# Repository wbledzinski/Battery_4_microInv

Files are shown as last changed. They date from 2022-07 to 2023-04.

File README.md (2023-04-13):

# Battery controller for On-grid microinverter 
36V li-ion battery controller cooperating with grid-tied microinverter
## 10A 35-42V battery; 450W grid-tie microinverter

2nd version of controller HW, connected to Microinverter and four e-scooter batteries
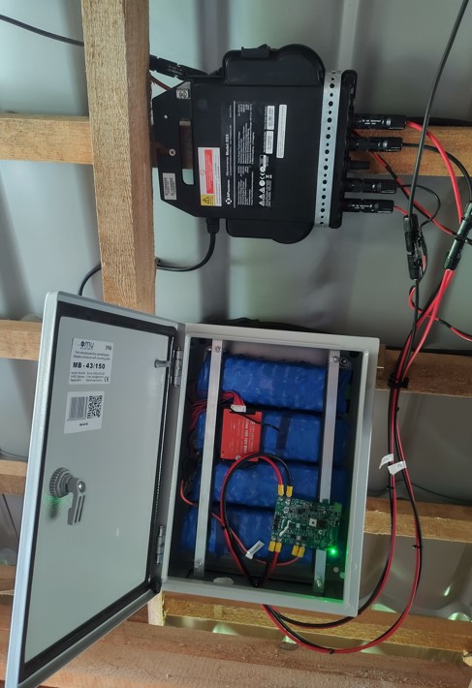
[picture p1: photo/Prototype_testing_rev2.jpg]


###  About this project
Main idea is to connect 10S 36V/42V li-ion e-scooter/e-bike battery to grid-tied PV installation.
It can be done because microinverters use low voltage input (MPP is ~40V).
So e-scooter battery has voltage exactly in operational range of microinverter and PV panel.

###  What exactly does this device?
Monitors energy consumption by microinverter. In case of inverter fault this device stores PV energy in battery.
After dusk energy stored in battery might be tranfered via inverter to mains network.

###  Why that idea?
It's because photovoltaics is very popular in village area where i've built my house. The result is that mains voltage is to high to properly operate any inverter around noon on sunny, cloudless day.

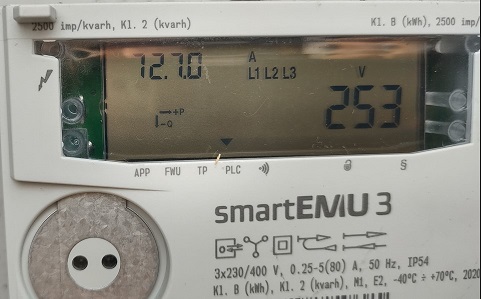
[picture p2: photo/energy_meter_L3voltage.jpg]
Energy meter phase L3 voltage measurement, during *inverters fight*


During sunny day my inverters (and neighbours' as well) switch off several times. That causes loses in energy production, because at possible peak production my PV array does not generate energy at all. 

Solution is to detect inverter fault and switch PV to charge battery - at the same time waiting for inverter to recover. Usually it's less than 10 minutes. But it happens dozens times during sunny day. Energy from battery is transferred to inverter (and mains) after dusk.

###  Modes of operation

user can configure controller in 3 modes:
- 1st mode is to tranfer energy from PV to inverter, charge battery only when inverter cautches fault; finally after dusk controller connects battery to microinverter to transfer stored  energy from battery to mains
- 2nd mode is to store energy in battery and connect inverter when battery is full. Then it will discharge battery after dusk
- 3rd mode is to tranfer energy from PV to inverter, charge battery only when inverter cautches fault; no battery discharge

###  Delayed discharge
My 2kW PV installation based on microinverters, uses 5 PV panels, 11A each, and 5 microinverters.
Connecting 5 batteries with controllers, I can set discharge delay independently for each controller.
result is that i can discharge them one by one thru the night, making it possible to consume that energy by fridge, lighting and other appliances.

###  Operation statistics
Firmware has built-in statistics counters, to estimate amount of energy transfered, recovered, number of microinverter faults

It suprised me, but statistics shows that some inverters have more faults than others, despite that they are all connected in parallel to the same electrical network

Real statistics after 3 days of operation:
------------------------------------------
Battery size 20Ah 10S battery, summertime, single energy bank:
- Inverter not operational 14587 seconds
- energy stored in battery due to lack of inverter operation; Wh 1781
- energy transferred from battery after dusk: Wh 1003
- energy transferred from PV to microinverter: Wh 8000
- number of inverter reset procedure launches: 6 (inverter not working > 30minutes)

Real statistics, from dec 2022 to apr 2023:
-----------------------------------------
Battery size 20Ah 10S battery, wintertime, single energy bank:
- Inverter not operational 655876 seconds (182 hours)
- battery too cold to charge 336885 seconds (93 hours) - energy not transfered to mains and not stored in battery (too cold)
- energy transferred from battery after dusk: Wh 16250
- energy transferred from PV to microinverter: Wh 84890

###  What it really does
below you see energy consumption and production as it's seen by energy distribution company.
blue is consumption, pink is production. Marked in red is what my system generates after dusk.
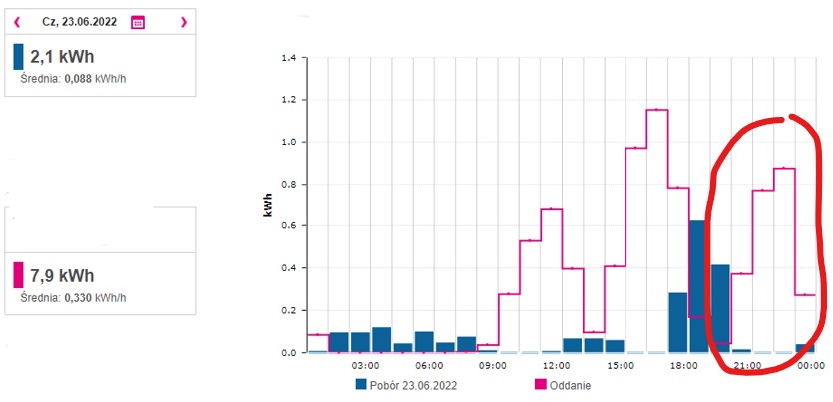
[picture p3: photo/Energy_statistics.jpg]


###  This version is in testing phase
A few pieces assembled, in-field testing in progress.

### Simplified operation algorithm
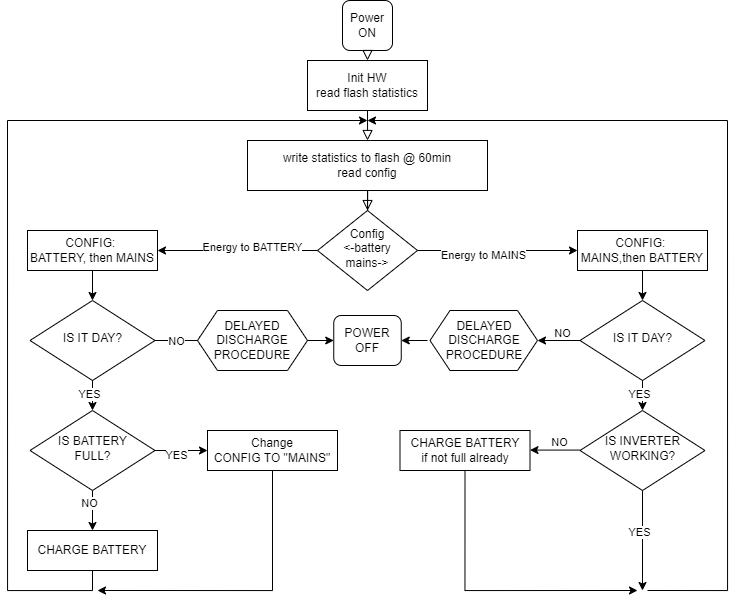
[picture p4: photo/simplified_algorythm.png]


###  what is working
- monitors Inverter operation, connects battery when inverter not operational
- after sunset properly counts delay time and after timeout connects battery to microinverter
- controls current consumption by microinverter, during daytime to decide whether charge battery or not
- controls current consumption by microinverter, during nighttime, to prevent excessive current consumption from battery: sometimes it happens -> controller resets microinverter MPP by cycling power
- overtemperature protection
- recent version (nov 2022) added under temperature charging protection

###  what is not working or not implemented
- ESP32, not implemented, HW 3v3 voltage rail is too weak to supply ESP32
- no implementation of any kind of watchdog
- no implementation of any kind of power saving mode
- SD-Card logging not implemented (to create detailed statistics or charts later)
- no RTC, might be usefull to create detailed statistics

###  HW Testing: Battery discharge
below is Pic during battery discharge ~13A, HW rev 01
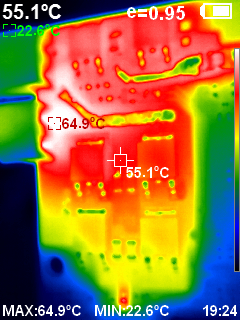
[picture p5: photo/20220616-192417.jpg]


below is Pic during battery discharge ~12A, HW rev 02
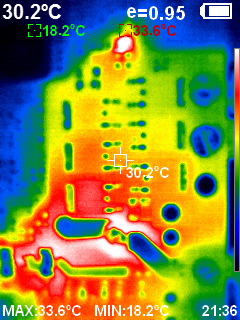
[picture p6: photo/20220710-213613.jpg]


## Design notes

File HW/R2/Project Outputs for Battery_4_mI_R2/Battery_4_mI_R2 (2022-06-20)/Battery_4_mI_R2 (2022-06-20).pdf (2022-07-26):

Comment | Description | Designator | Footprint | LibRef | LogicalDesignator | Manufacturer | Manufacturer 1 | Manufacturer 2 | Manufacturer Part Number | Manufacturer Part Number 1 | Manufacturer Part Number 2 | PartType | Price10 | Price1k | Pricing | Quantity | Supplier | Supplier 1 | Supplier 2 | Supplier Currency 1 | Supplier Currency 2 | Supplier Order Qty 1 | Supplier Order Qty 2 | Supplier Part Number | Supplier Part Number 1 | Supplier Part Number 2 | Supplier Stock 1 | Supplier Stock 2 | Supplier Subtotal 1 | Supplier Subtotal 2 | Supplier Unit Price 1 | Supplier Unit Price 2 | Value | Layer
1u/100 | X7R chip capacitor | C1, C2, C3, C28, C29 | CAP_1206 | CAP_B_1u_100_1 206_X7R | C1, C2, C3, C28, C29 | AVX | | | 12061C105KAT2A | | | 1u/100 | 0.22 | 0.2 | | 5 | TME | FARNELL | | | | | | 12061C105KAT2A | 2112837 | | | | | | | | 1u/100 | Top
4.7u/25 | X5R chip capacitor | C4, C5 | CAP_1210 | CAP_B_4.7u_25_1 210_X5R | C4, C5 | YAGEO | | | CC1210KKX5R8BB 475 | | | 4.7u/25 | 0.17 | 0.007 | | 2 | TME | Farnell | | | | | | CC1210KKX5R847 5 | 1833828 | | | | | | | | 4.7u/25 | Top
100n/50 | X7R chip capacitor | C6, C11, C12, C22, C23, C26, C32, C35, C38, C39, C40, C41, C42, C44 | CAP_0603 | CAP_B_100n_50_ 0603_X7R | C6, C11, C12, C22, C23, C26, C32, C35, C38, C39, C40, C41, C42, C44 | SAMSUNG | | | CL10B104KB8NNN C | | | 100n/50 | 0.1 | 0.006 | | 14 | TME | | | | | | | CL10B104KB8NNN C | | | | | | | | | 100n/50 | Top, Bottom
10u/25 | X5R chip capacitor | C7 | CAP_1206 | CAP_B_10u_25_1 206_X5R | C7 | SAMSUNG | | | CL31A106KAHNN NE | | | 10u/25 | 0.08 | 0.045 | | 1 | TME | Farnell | | | | | | CL31A106KAHNN NE | 2426961 | | | | | | | | 10u/25 | Top
10u/16 | X7R chip capacitor | C8, C9, C10, C27, C30 | CAP_1206 | CAP_B_10u_16_1 206_X7R | C8, C9, C10, C27, C30 | KYOCERA | | | CM316X7R106K16 AT | | | 10u/16 | 0.08 | 0.045 | | 5 | TME | Farnell | | | | | | CM316X7R106K16 AT | 2070502 | | | | | | | | 10u/16 | Top
39p/100 | COG chip capacitor | C13 | CAP_0603 | CAP_B_39p_100_ 0603_COG | C13 | | | | | | | 39p/100 | 0.1 | 0.006 | | 1 | TME | Farnell | | | | | | | | | | | | | | | 39p/100 | Top
10n/100 | X7R chip capacitor | C14, C33, C46 | CAP_0603 | CAP_B_10n_100_ 0603_X7R | C14, C33, C46 | SAMSUNG | | | CL10B103KC8NNN C | | | 10n/100 | 0.01 | 0.0027 | | 3 | TME | Farnell | | | | | | CL10B103KC8NNN C | 1327671 | | | | | | | | 10n/100 | Top
1n/100 | X7R chip capacitor | C15, C16, C18, C19, C20, C21 | CAP_0603 | CAP_B_1n_100_0 603_X7R | C15, C16, C18, C19, C20, C21 | SAMSUNG | | | CL10B102KC8NNN C | | | 1n/100 | 0.1 | 0.006 | | 6 | TME | Farnell | | | | | | CL10B102KC8NNN C | 1833874 | | | | | | | | 1n/100 | Top
47n/25 | X7R chip capacitor | C17 | CAP_0603 | CAP_B_47n_25_0 603_X7R | C17 | | | | | | | 47n/25 | | | | 1 | TME | Farnell | | | | | | | | | | | | | | | 47n/25 | Top
1u/16 | X7R chip capacitor | C24, C25, C31 | CAP_0603 | CAP_B_1u_16_06 03_X7R | C24, C25, C31 | SAMSUNG | | | CL10B105KO8NN NC | | | 1u/16 | 0.1 | 0.012 | | 3 | TME | Farnell | | | | | | CL10B105KO8NN NC | 2310404 | | | | | | | | 1u/16 | Top, Bottom
100n/100 | X7R chip capacitor | C34 | CAP_0805 | CAP_B_100n_100 _0805_X7R | C34 | AVX | | | 08051C104KAZ2A | | | 100n/100 | 0.1 | 0.03 | | 1 | TME | FARNELL | | | | | | 08051C104KAZ2A | 1301805 | | | | | | | | 100n/100 | Top
22p/50 | X7R chip capacitor | C36, C37 | CAP_0603 | CAP_B_22p_50_0 603_X7R | C36, C37 | | | | | | | 22p/50 | 0.01 | 0.0027 | | 2 | TME | Farnell | | | | | | | | | | | | | | | 22p/50 | Top
2u2/100 | X7R chip capacitor | C43, C48 | CAP_1210 | CAP_B_2u2_100_ 1210_X7R | C43, C48 | KEMET | | | C1210C225M1RAC TU | | | 2u2/100 | 0.55 | 0.35 | | 2 | TME | FARNELL | | | | | | CL32B225KCJSNN E | 1838747 | | | | | | | | 2u2/100 | Top
1n/2k | X7R chip capacitor | C45, C47 | CAP_1206 | CAP_B_1n_2k_120 6_X7R | C45, C47 | MULTICOMP | | | MC1206B102K202 CT | | | 1n/2k | 0.3 | 0.02 | | 2 | FARNELL | FARNELL | | | | | | 1875512 | 1875512 | | | | | | | | 1n/2k | Top
Shottky 0.25A/100V BAT46GW | Shottky Diode trr 4ns 0,43V @ 0.05A 0.75V@0.25A | D1, D7, D8, D9, D16, D17 | SOD_123 | D_0.25_100_BAT4 6GWX | D1, D7, D8, D9, D16, D17 | Nexperia | | | BAT46GWX 934070363115 | | | Shottky 0.25A/100V BAT46GW | 0.062 | 0.04 | | 6 | TME | FARNELL | | | | | | BAT46GWX | 2760404 | | | | | | | | Shottky 0.25A/100V BAT46GW | Top
Green LED KP-1608SGC | Diode LED SMD 2.2V @ 20mA 15mcd | D2, D3, D10, D11, D12, D13 | LED_0603_GREEN | D_LED_0603_GRE EN | D2, D3, D10, D11, D12, D13 | KINGBRIGHT | | | KP-1608SGC | | | Green LED KP-1608SGC | 0.05 | 0.03 | | 6 | TME | Farnell | | | | | | KP-1608SGC | 8529833 | | | | | | | | Green LED KP-1608SGC | Top
fast shottky 1A/200V | Shottky Diode 0,9V @ 1A trr=15ns 7pF | D4 | SMA_DO-214AC | D_1A_200_ES1D | D4 | FAIRCHILD | | | ES1D | | | fast shottky 1A/200V | 0.41 | 0.06 | | 1 | TME | FARNELL | | | | | | ES1D | 1467489 | | | | | | | | fast shottky 1A/200V | Top
DNP | | D5, D6, D14 | D_MINIMELF | D_LL4148_MMELF | D5, D6, D14 | ON SEMICONDUCTOR (FAIRCHILD) | | | FDLL4148 | | | DNP | | | 50=0.0128, 250=0.0113, 1000=0.0092, 5000=0.0078, 20000=0.0074 (USD) | 3 | | TME | | | | | | | FDLL4148 | | | | | | | | | Top
78 | transil jednostronny 400W | D15 | SMA_DO-214AC | D_TR_UNI_SMAJ7 8A | D15 | MULTICOMP | | | SMAJ78A | | | 78 | 0.2 | 0.1 | | 1 | TME | Farnell | | | | | | SMAJ78A-LF | 1579024 | | | | | | | | Transil_U_400W | Top
5.08 TB V | THT 5,08mm, WE 691311500002 (rev1), NINIGI , MLX | J1, J2, J3, J7, J8 | CON_1x2_5.08TB | CON_1x2_TB_5.0 8V | J1, J2, J3, J7, J8 | Wurth Electronics | | | 691311500002 | | | 5.08 TB V | | | | 5 | | TME | Digi-Key | | | | | | TBG-5-PB-2P/GN | 732-2052-ND | | | | | $0.33 | | | Top
1x3p 2.54mm GP | THT 2,54 goldpin | J4 | CON_PIN1x3_THT | CON_1x3_GP_THT | J4 | TME | | | ZL201-03G | | | 1x3p 2.54mm GP | 0.15 | 0.1 | | 1 | TME | digi-key | | | | | | ZL201-03G | WM8073-ND | | | | | | | | 1x3p 2.54mm GP | Top
Micro SD 112C-TBAR-R02 lub 472192001 | Micro SD connector SMD, ATTEND 112C-TBAR-R02; MOLEX 472192001 | J5 | 112C_TXAR_R01 | CON_MicroSD | J5 | ATTEND | | | 112C-TBAR-R02 | | | Micro SD 112C-TBAR-R02 lub 472192001 | 0.8 | 0.65 | | 1 | TME | TME | | | | | | MCC-SDMICRO/1 | MCC-SDMICRO/1 | | | | | | | | Micro SD 112C-TBAR-R02 lub 472192001 | Bottom
1x6p 2.54mm | THT 2,54 goldpin | J6 | CON_PIN1x6_THT | CON_1x6_GP_THT | J6 | CONNFLY | | | DS1021-1*6SF1-1 | | | 1x6p 2.54mm | 0.15 | 0.1 | | 1 | TME | TME | | | | | | ZL201-06G | ZL201-06G | | | | | | | | 1x6p 2.54mm | Top
HEX/BCD | Zadajnik kodu | K1 | MECH_SW_HEXBC D | MECH_SW_HEXBC D | K1 | ECE | | | ERD116RSZ | | | HEX/BCD | 2.7 | 1.8 | | 1 | TME | TME | | | | | | ERD116RSZ | ERD116RSZ | | | | | | | | HEX/BCD | Top
22u 1.09A DLCSS075F-220M | shielded power inductor 1.09A Rdc=0,12 | L1 | IND_DER0705 | IND_22u_1.09A_D ER0705-22 | L1 | FERROCORE | | | DER0705-22 | | | 22u 1.09A DLCSS075F-220M | 0.45 | 0.4 | | 1 | MARITEX | TME | | | | | | DLCSS075F-220M | DER0705-22 | | | | | | | | 22u 1.09A DLCSS075F-220M | Top
DNP | 2A Rdc=0,15 SRF 250MHz, Resistor 0603 5% 0,1W | L2, R50, R68 | RES_0603 | IND_FB_300R_060 3, RES_10k_5p_0603 , RES_16k_5p_0603 | L2, R50, R68 | WE, [NoValue], YAGEO | | | 742792641, [NoValue] | | | DNP | .21, 0.01 | .08, 0.003 | | 3 | FARNELL, [NoValue], TME | FARNELL, [NoValue], TME | | | | | | 1635705RL, [NoValue] | 1635705, [NoValue] | | | | | | | | 300ohm@100MHz 1A, 10k 5%, 10k | Top
300ohm@100MHz 1A | 2A Rdc=0,15 SRF 250MHz | L3 | RES_0603 | IND_FB_300R_060 3 | L3 | WE | | | 742792641 | | | 300ohm@100MHz 1A | .21 | .08 | | 1 | FARNELL | FARNELL | | | | | | 1635705RL | 1635705 | | | | | | | | 300ohm@100MHz 1A | Top
BSS84PH6433 | 50V 130mA P Mosfet | Q1 | SOT23-3 | T_BSS84 | Q1 | INFINEON TECHNOLOGIES | | | BSS84PH6433 | | | BSS84PH6433 | | | 25=0.0345, 100=0.031, 500=0.0274, 2500=0.0246, 10000=0.023 (USD) | 1 | | TME | | | | | | | BSS84PH6433 | | | | | | | | | Top
DMG2301L-7 | 20V 3A P Mosfet | Q2 | SOT23-3 | T_DMG2301L-7 | Q2 | DIODES | | | DMG2301L-7 | | | DMG2301L-7 | | | | 1 | | FARNELL | | | | | | | 3127313 | | | | | | | | | Top
ZXMP10A13FTA | 100V 700mA P Mosfet | Q3 | SOT23-3 | T_ZXMP10A13FTA | Q3 | DIODES | | | ZXMP10A13FTA | | | ZXMP10A13FTA | | | | 1 | | FARNELL | | | | | | | 1843777 | | | | | | | | | Top
dnp | Resistor 1206 5% 0,25W | R1, R59, R60 | RES_1206 | RES_0R_5p_1206 | R1, R59, R60 | ROYAL OHM | | | 1206S4J0000T5E | | | dnp | 0.3 | 0.24 | | 3 | TME | Farnell | | | | | | SMD1206-0R | 9336974 | | | | | | | | 0R 5% | Top
2mR shunt | Resistor 2512 5% 1W | R2, R3 | RES_2512_shunt | RES_2mR_1p_251 2 | R2, R3 | YAGEO | | | | | | 2mR shunt | | 0.2 | | 2 | TME | FARNELL | | | | | | | | | | | | | | | 2mR shunt | Top
240k | Resistor 0603 5% 0,1W | R4 | RES_0603 | RES_105k_5p_060 3 | R4 | | | | | | | 240k | 0.01 | 0.003 | | 1 | TME | TME | | | | | | | | | | | | | | | 240k | Top
120k | Resistor 0603 5% 0,1W | R5 | RES_0603 | RES_62k_5p_0603 | R5 | YAGEO | | | | | | 120k | 0.01 | 0.003 | | 1 | TME | Farnell | | | | | | | | | | | | | | | 120k | Top
470k | Resistor 0603 5% 0,1W | R6, R37 | RES_0603 | RES_1k_5p_0603 | R6, R37 | YAGEO | | | | | | 470k | 0.01 | 0.003 | | 2 | TME | TME | | | | | | | | | | | | | | | 470k | Top
10k | Resistor 0603 5% 0,1W | R7, R43, R44, R45, R46, R56, R57 | RES_0603 | RES_16k_5p_0603 | R7, R43, R44, R45, R46, R56, R57 | YAGEO | | | | | | 10k | 0.01 | 0.003 | | 7 | TME | TME | | | | | | | | | | | | | | | 10k | Top
1k 5% | Resistor 0603 5% 0,1W | R8, R9, R10, R11, R38, R47, R49, R52, R54, R65 | RES_0603 | RES_1k_5p_0603 | R8, R9, R10, R11, R38, R47, R49, R52, R54, R65 | YAGEO | | | | | | 1k 5% | 0.01 | 0.003 | | 10 | TME | TME | | | | | | SMD0603-1K | SMD0603-1K | | | | | | | | 1k 5% | Top
10k 5% | Resistor 0603 5% 0,1W | R12, R13, R24, R27, R29, R30, R31, R32, R33, R35, R39, R48, R51, R55, R58, R62, R63, R67 | RES_0603 | RES_10k_5p_0603 | R12, R13, R24, R27, R29, R30, R31, R32, R33, R35, R39, R48, R51, R55, R58, R62, R63, R67 | | | | | | | 10k 5% | 0.01 | 0.003 | | 18 | | | | | | | | | | | | | | | | | 10k 5% | Top, Bottom
16k 5% | Resistor 0603 5% 0,1W | R14, R40 | RES_0603 | RES_16k_5p_0603 | R14, R40 | YAGEO | | | | | | 16k 5% | 0.01 | 0.003 | | 2 | TME | TME | | | | | | | | | | | | | | | 16k 5% | Top
510 5% | Resistor 0603 5% 0,1W | R15 | RES_0603 | RES_510_5p_0603 | R15 | | | | | | | 510 5% | 0.01 | 0.003 | | 1 | TME | TME | | | | | | SMD0603-510R | SMD0603-510R | | | | | | | | 510 5% | Top
100k 5% | Resistor 0603 5% 0,1W | R16, R21, R70 | RES_0603 | RES_100k_5p_060 3 | R16, R21, R70 | | | | | | | 100k 5% | 0.01 | 0.003 | | 3 | TME | TME | | | | | | | | | | | | | | | 100k 5% | Top
47k 5% | Resistor 0603 5% 0,1W | R17, R69 | RES_0603 | RES_47k_5p_0603 | R17, R69 | YAGEO | | | | | | 47k 5% | 0.01 | 0.003 | | 2 | TME | TME | | | | | | SMD0603-47K | SMD0603-47K | | | | | | | | 47k 5% | Top
20k 5% | Resistor 0603 5% 0,1W | R18 | RES_0603 | RES_20k_5p_0603 | R18 | ROYAL OHM | | | 0603SAJ0203T5E | | | 20k 5% | 0.01 | 0.003 | | 1 | TME | Farnell | | | | | | SMD0603-20K | 1799402 | | | | | | | | 20k 5% | Top
22k 5% | Resistor 0603 5% 0,1W | R19, R20 | RES_0603 | RES_22k_5p_0603 | R19, R20 | YAGEO | | | | | | 22k 5% | 0.01 | 0.003 | | 2 | TME | TME | | | | | | SMD0603-22K | SMD0603-22K | | | | | | | | 22k 5% | Top
49.9k | Resistor 0603 5% 0,1W | R22, R23 | RES_0603 | RES_1k_5p_0603 | R22, R23 | YAGEO | | | | | | 49.9k | 0.01 | 0.003 | | 2 | TME | TME | | | | | | | | | | | | | | | 49.9k | Top
4M7 5% | Resistor 1206 5% 0,25W | R25, R26, R66, R72 | RES_1206 | RES_4M7_5p_120 6 | R25, R26, R66, R72 | ROYAL OHM | | | 1206S4J0475T5E | | | 4M7 5% | 0.009 | 0.004 | | 4 | TME | | | | | | | SMD1206-4M7 | | | | | | | | | 4M7 5% | Top
330 5% | Resistor 0603 5% 0,1W | R28, R41, R42, R53, R71 | RES_0603 | RES_330R_5p_060 3 | R28, R41, R42, R53, R71 | | | | | | | 330 5% | 0.01 | 0.003 | | 5 | TME | TME | | | | | | SMD0603-330R | SMD0603-330R | | | | | | | | 330 5% | Top
220k | Resistor 0603 5% 0,1W | R34, R64 | RES_0603 | RES_100k_5p_060 3 | R34, R64 | | | | | | | 220k | 0.01 | 0.003 | | 2 | TME | TME | | | | | | | | | | | | | | | 220k | Top
4k7 | Resistor 0603 5% 0,1W | R36 | RES_0603 | RES_100k_5p_060 3 | R36 | | | | | | | 4k7 | 0.01 | 0.003 | | 1 | TME | TME | | | | | | | | | | | | | | | 4k7 | Top
68 5% | 0603 ,1W | R61 | RES_0603 | RES_68_5p_0603 | R61 | ROYAL OHM | | | 0603SAJ0680T5E | | | 68 5% | 0.09 | 0.003 | | 1 | TME | | | | | | | SMD0603-68R | | | | | | | | | 68 5% | Top
NTCS0603E3683F HT | Thermistor 0603 ,063W Stała materiałowa B 3985K | RT1, RT2, RT3 | RES_0603 | REST_10k_0603 | RT1, RT2, RT3 | VISHAY | | | NTCS0603E3683F HT | | | NTCS0603E3683F HT | 0.3 | 0.2 | | 3 | TME | TME | | | | | | NTCS0603E3683F HT | NTCS0603E3683F HT | | | | | | | | NTCS0603E3683F HT | Top
50VAC 1kA | warystor S14 30VAC 38VDC 1kA 9J@2ms | RV1 | RES_VAR_S14 | RESV_38V_1kA_T HT | RV1 | EPCOS | | | | | | 50VAC 1kA | 0.83 | 0.38 | | 1 | TME | TME | | | | | | SIOV-S14K60 | SIOV-S14K30 | | | | | | | | 50VAC 1kA | Top
IPD034N06N3GAT MA1 | 60V N-Mosfet 100A 60V 3.54mohm | T1, T2, T3, T4, T6, T7, T12, T13, T14 | DPAK_369C_issue D | T_IPD034N06N3 | T1, T2, T3, T4, T6, T7, T12, T13, T14 | INFINEON | | | IPD034N06N3GAT MA1 | | | IPD034N06N3GAT MA1 | | | 1=1.2696, 3=1.0935, 10=0.8782, 100=0.7623, 1000=0.7097 (USD) | 9 | TME | TME | Farnell | | | | | IPD034N06N3GAT MA1 | IPD034N06N3GAT MA1 | 2443392RL | | | | | | | | Top
2N7002-7-F | 60V 0.21A N mosfet | T5, T8, T9, T10, T15, T16 | SOT23-3 | T_2N7002 | T5, T8, T9, T10, T15, T16 | DIODES | | | 2N7002-7-F | | | 2N7002-7-F | | | | 6 | TME | TME | | | | | | 2N7002-7-F | 2N7002-7-F | | | | | | | | 2N7002-7-F | Top
HCPL817-300E | HCPL817-300E '0' ctr 50-600% if 20ma ic 30ma vce 70V vr 4v | T11 | HCPL-817 | T_HCPL817-300E | T11 | | | | HCPL-817-36BE | | | HCPL817-300E | | | | 1 | | Farnell | | | | | | | 1244566 | | | | | | | | | Top
TPS57160QDGQR Q1 | 116uA quescient current | U1 | MSOP10_DQG_S_ PDSO_G10 | IC_TPS57160QDG QRQ1 | U1 | Texas Instruments | | | TPS57160QDGQR Q1 | | | TPS57160QDGQR Q1 | | | 1=3.02, 10=2.716, 100=2.225, 500=1.89414, 1000=1.59747 (GBP) | 1 | | Farnell | Avnet | | | | | | 2492454 | TPS57160QDGQR Q1 | | | | | | | | Top
LMV772QMM/NO PB | LowOffset,LowNo ise,RROOperation alAmplifier | U2 | MSOP8_3x3_846A D-01 | IC_LMV772QMM | U2 | TI National Semiconductor | | | LMV772QMM/NO PB | | | LMV772QMM/NO PB | | | | 1 | | Mouser | | | | | | | 926-LMV772QMM/NO PB | | | | | | $2.66 | | | Top
WT8266-S2 | | U3 | MOD_WT8266-S2 | MOD_WT8266-S2 | U3 | xiaoe | | | WT8266-S2 | | | WT8266-S2 | 8 | 6 | | 1 | maritex | TME | | | | | | WIFI-WT8266-S2 | WT8266-S2 | | | | | | | | WT8266-S2 | Bottom
MCP1703A-3302 | LDO=210mV 6V DC max, Iq 120uA, Cout 1u ceramic | U4 | sot223 | IC_MCP1825S-3.3_SOT223 | U4 | Microchip | | | MCP1703A-3302 | | | MCP1703A-3302 | 1 | 0.75 | | 1 | TME | Farnell | | | | | | MCP1825S-3302ED | | | | | | | | | MCP1703A-3302 | Top
IC_STM32L431RC T6_LQFP64 | LQFP64, 10x10mm | U5 | LQFP64_10x10 | IC_STM32L431RC T6_LQFP64 | U5 | STMicroelectronic s | | | STM32L431RCT6 | | | IC_STM32L431RC T6_LQFP64 | | | | 1 | | Arrow | TME | | | | | | STM32L431RCT6 | STM32L431RCT6 | | | | | $3.52 | | | Top
OSCX_8M_5,0x3,2 | SMD 5,0x3,2mm xtal drive 100uW max; ESR 150 ohm | X1 | X_5.0X3.2 | OSCX_8M_5,0x3,2 | X1 | Abracon | | | ABM3-8.000MHZ-D2Y-T | | | OSCX_8M_5,0x3,2 | | | | 1 | | | | | | | | | | | | | | | $0.52632 | | | Top

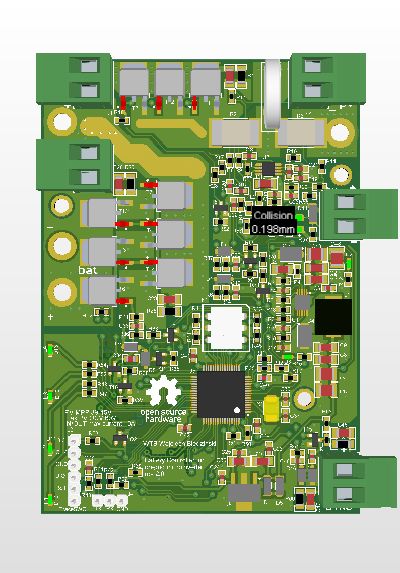
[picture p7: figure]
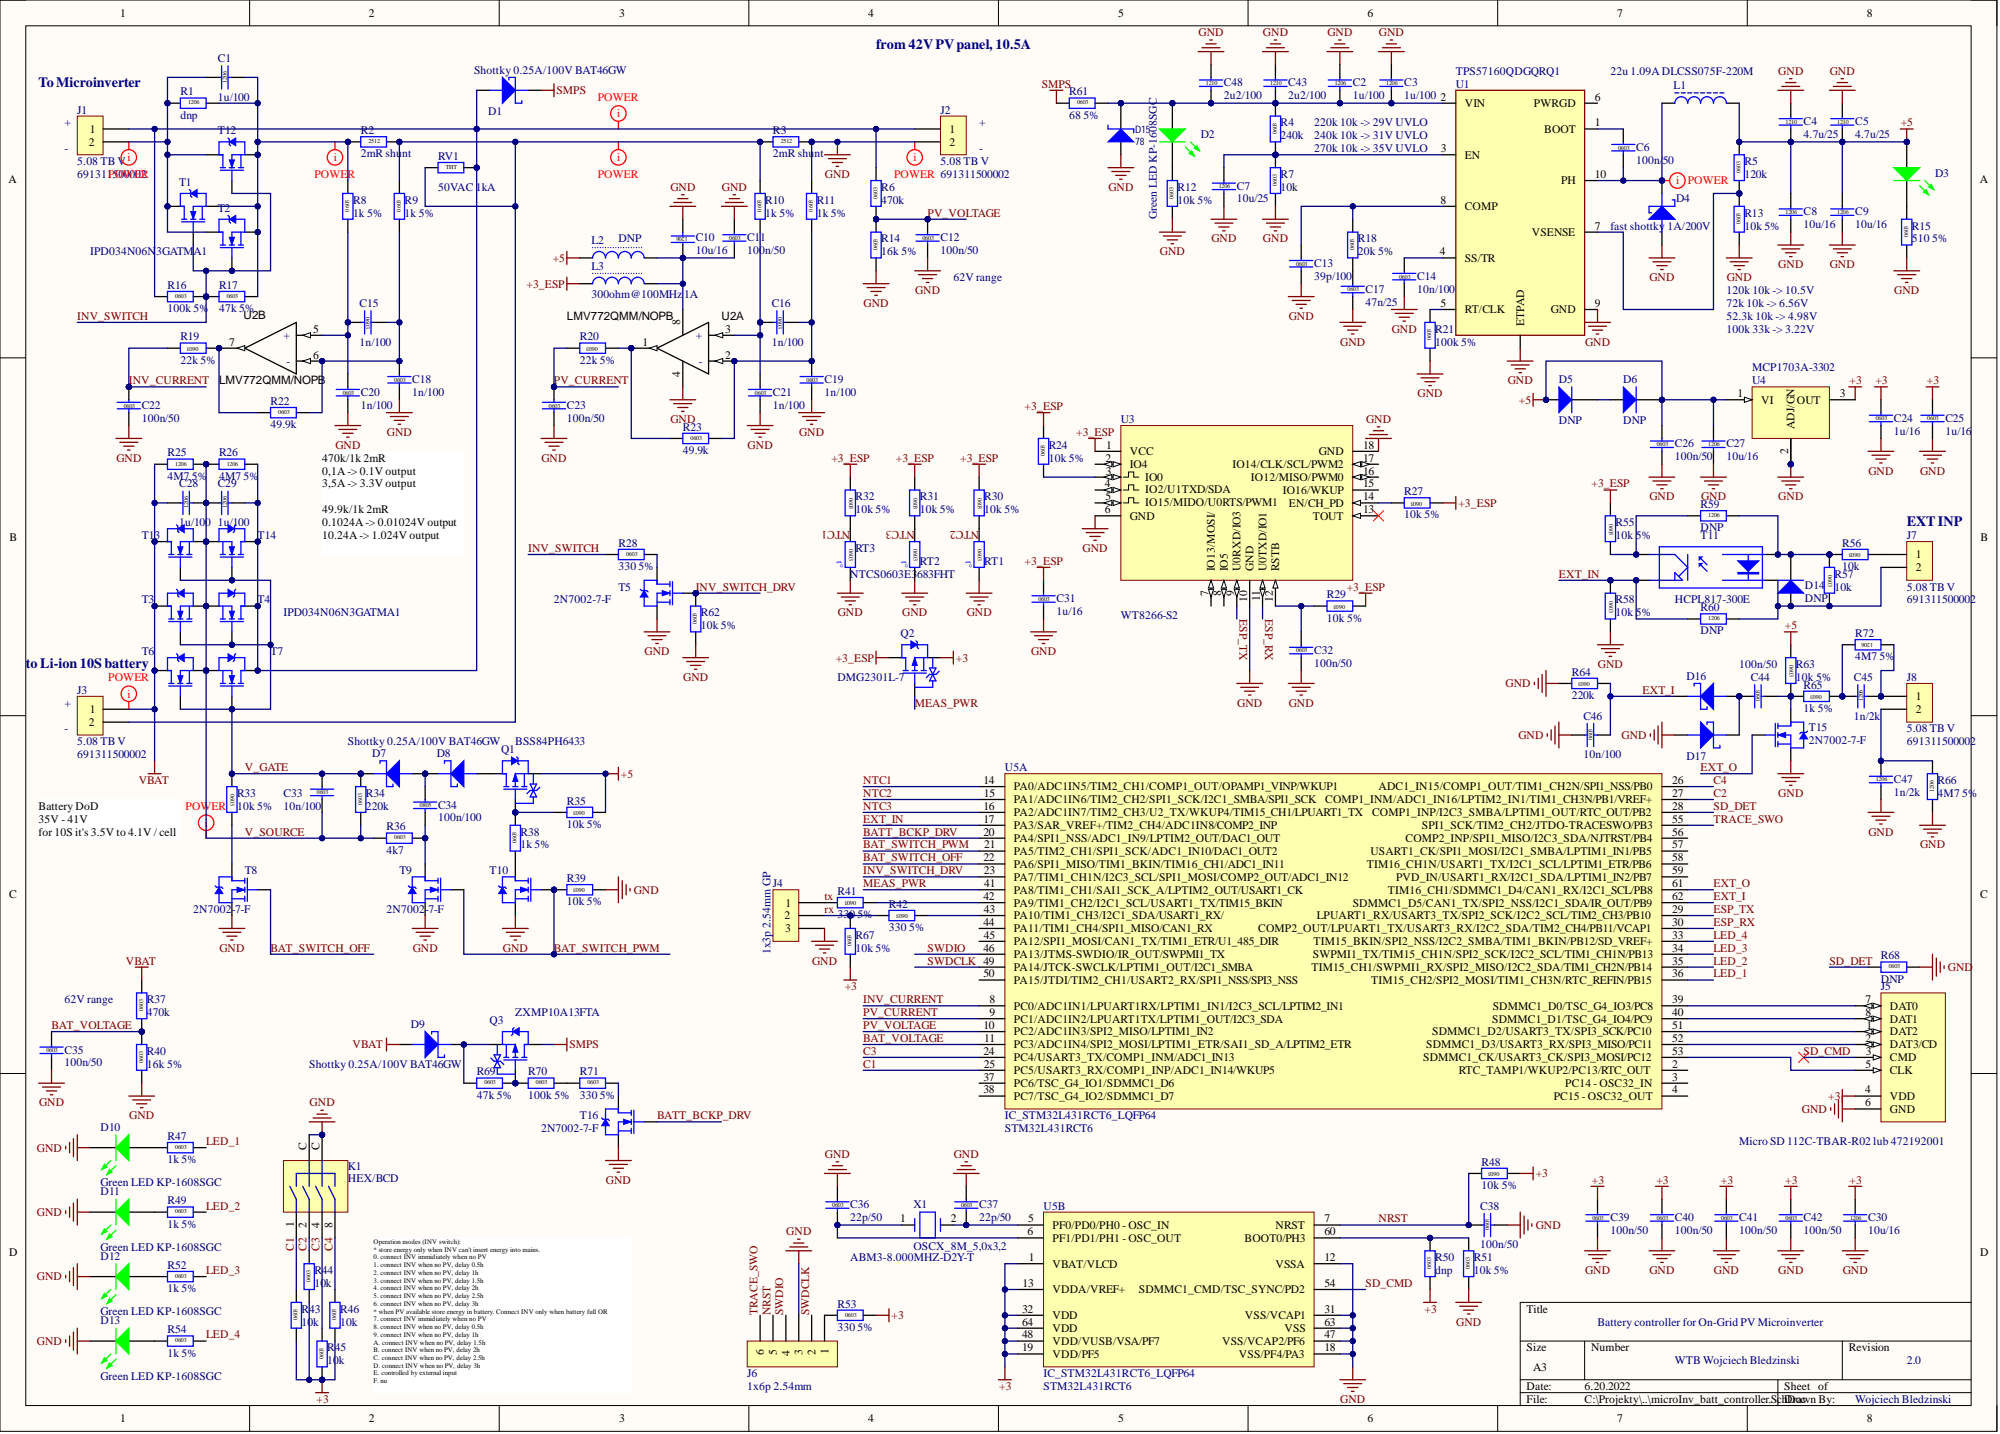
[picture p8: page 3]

to Li-ion 10S battery

i | V_GATE

EXT_O

Battery DoD
for 10S it's 3.5V to 4.1V / cell

Micro SD 112C-TBAR-R02 lub 472192001

Operation modes (INV switch):
* store energy only when INV can't insert energy into mains.
0. connect INV immidiately when no PV
1. connect INV when no PV, delay 0.5h
2. connect INV when no PV, delay 1h
3. connect INV when no PV, delay 1.5h
4. connect INV when no PV, delay 2h
5. connect INV when no PV, delay 2.5h
6. connect INV when no PV, delay 3h

* when PV available store energy in battery. Connect INV only when battery full OR
7. connect INV immidiately when no PV
8. connect INV when no PV, delay 0.5h
9. connect INV when no PV, delay 1h
A. connect INV when no PV, delay 1.5h
B. connect INV when no PV, delay 2h
C. connect INV when no PV, delay 2.5h
D. connect INV when no PV, delay 3h
E. controlled by external input

Battery controller for On-Grid PV Microinverter

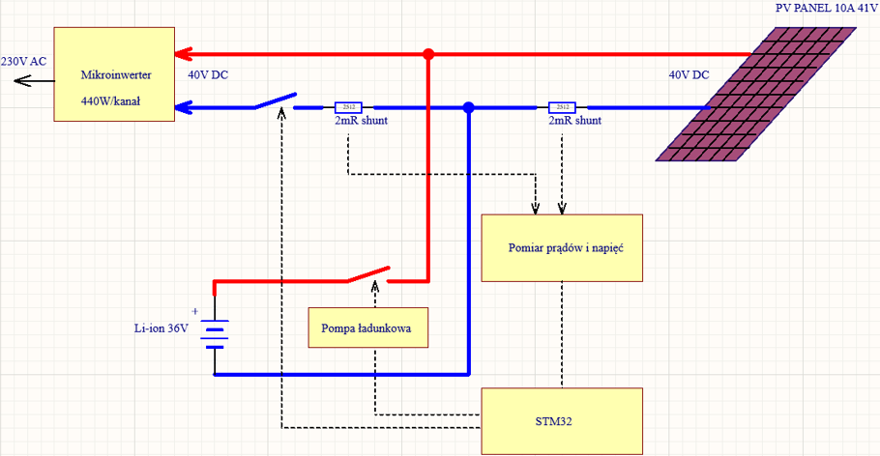
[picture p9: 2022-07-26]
photo/block diagram.png

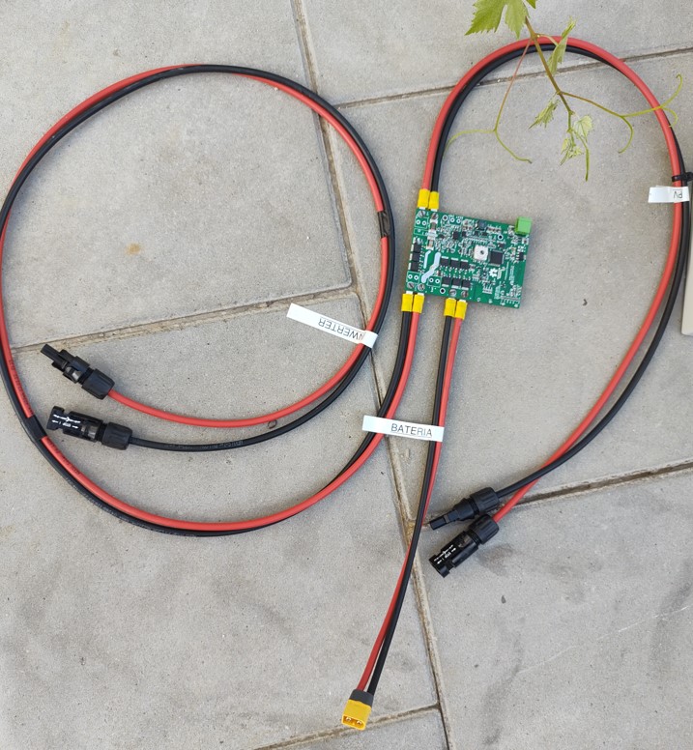
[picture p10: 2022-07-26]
photo/HW_rev2.jpg

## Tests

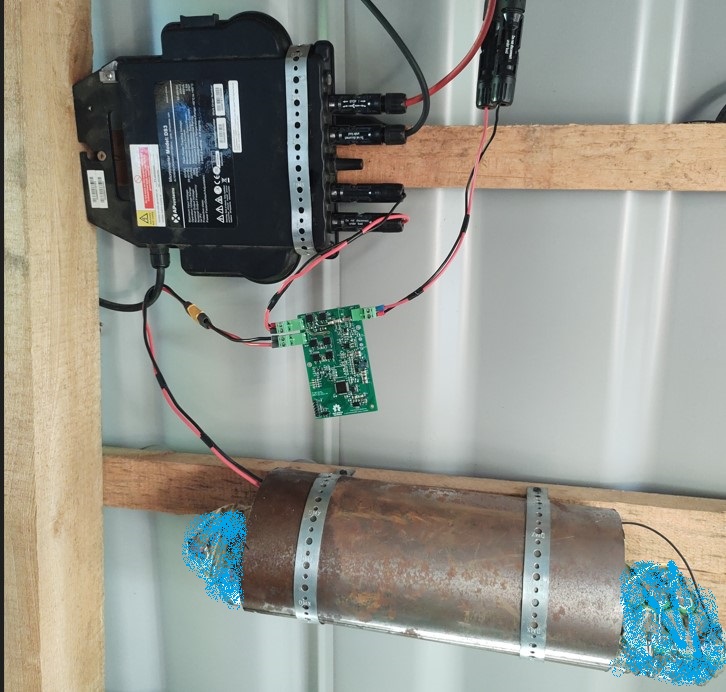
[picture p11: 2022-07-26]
photo/Prototype_testing.jpg

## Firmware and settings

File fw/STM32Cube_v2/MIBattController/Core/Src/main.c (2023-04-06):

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
/* Includes ------------------------------------------------------------------*/
#include "main.h"
#include "cmsis_os.h"

/* USER CODE BEGIN Includes */
#include "math.h"
#include "string.h"
#include "stdio.h"
/* USER CODE END Includes */

/* USER CODE BEGIN PD */
//#define DEBUG_EN		1	//comment to get production functionality
//#define TESTING_VALUES	1	//comment to get production values
#define PRINTF_DEBUG		2	//defined will compile printf for alghoritm debug
#ifdef PRINTF_DEBUG
# define DEBUG_PRINT(x) sprintf(TxBuffer+strlen(TxBuffer), x);
#else
# define DEBUG_PRINT(x) do {} while (0)
#endif
#define FLASHSTATSAVE_PERIOD	0	//0- stats saved every hour; 1-stats saved only when fully ch/discharged
#define HW_VER		02		//1st rev 01; 2nd rev 02; etc.
#ifndef TESTING_VALUES		//********* below are PRODUCTION VALUES ************
#define TICKS_ONESECOND	0	//counter ticks for one second (default 0)
#define TICKS_ONEMINUTE	59	//counter ticks for one minute (default 59)
#define TICKS_ONEHOUR	59	//counter ticks for one hour (default 59)
#define TICKS_ONEDAY	23	//counter ticks for one day (default 23)
#define RX_BFR_SIZE 127		//uart 1
#define TX_BFR_SIZE 1023		//uart 1
#define NO_FLASH_PAGES	52	//number of flash pages for storing statistics to flash
#define MOSFET_MAX_TEMP		70	//Mosfet max operating temperature *C
#define MIN_CHARGING_TEMP	4	//PCB minimum temperature that allows high charging current for battery charging (> INV_CURRENT_MIN_NIGHT limit, 0.3A). <INV_CURRENT_MIN_NIGHT still possible;
#define PV_CURRENT_MIN		320	//in 0.001A, min PV curent to assume that it is daylight - for alghorithm. after HAL_ADC_Calibration values for current circuit are of bigger values - instead 120mA it returns 350mA
								//current>PV_CURRENT_MIN to enter DAYTIME; (PV_CURRENT_MIN - PV_CURRENT_HYST) to keep "DAYTIME"; current<(PV_CURRENT_MIN - PV_CURRENT_HYST) to enter nightime; current<PV_CURRENT_MIN to keep nightime
								//this value sets minimal level of current that can make inverter working without excessive reactive power at mains side(AC current)
#define PV_CURRENT_HYST		70	//in 0.001A, PV curent hysteresis, to prevent frequent change chg/dschg during dusk and dawn
#define INV_CURRENT_MIN_DAY		230	//in 0.001A, min inverter current to assume that inv transfers energy to mains. usually slightly smaller than PV_CURRENT_MIN
								//to prevent switchung battery on/off at daytime at dusk . difference should cover current measurement error for small currents between channels
#define INV_CURRENT_MIN_NIGHT		270	//in 0.001A, min inverter current to assume that inv transfers energy to mains.
#define INV_CURRENT_MAX		13500	//in 0.001A, maximum inverter current during batttery discharging. Helps prevent overheating
#define INV_CURR_SC			16500	//in 0.001A, more than that is considered as short circuit, all will be shut down without delay (in 1 second)
#define PV_OCV_VOLGATE		435	//in 0.1V, OCV voltage for PV panel without load (minimal PV OCV voltage for hot, cloudy day)
#define PV_MIN_OP_VOLTAGE	330	//in 0.1V, minimal operational voltage for PV panel when working with inverter. prevents INV from overloading PV.
#define BATT_CRITICAL_MIN_VOLTAGE	240	//in 0.1V, min limit for charging
#define BATT_MIN_VOLTAGE	348	//in 0.1V, consider min limit for discharging with "-hysteresisMIN"
#define BATT_MAX_VOLTAGE	403	//in 0.1V, consider max limit for charging with "+hysteresisMAX"
#define BATT_VOLTAGE_MAXHYSTERESIS	18	//in 0.1V, to prevent frequent switching chg/dschg at max voltage
#define BATT_VOLTAGE_MINHYSTERESIS	17	//in 0.1V, to prevent frequent switching chg/dschg at min voltage/ 15 makes multiple discharges at dusk - confuses statistics; maybe longer nigh-timeout will help
#define SECONDS_HOUR		((TICKS_ONEMINUTE+1)*(TICKS_ONEHOUR+1))	//to calculate Watt-hours from Watt-seconds
#define LEDSTATUS_TIMER_LONG		9		//10 seconds cycle
#define LEDSTATUS_TIMER_MED			3		//4 seconds cycle
#define LEDSTATUS_TIMER_SHORT		1		//2 seconds cycle
#define TIME2RESET_INV				2500	//30min/1800s, 42m/2500s; if INV not working for longer than ... seconds perform reset procedure
#define TIME2OVLD_INV				35		//maximum time of overload,seconds, during battery discharge
#define TIME_LOW_I_4NIGHT			1800	//30min/1800s, 42m/2500s; low PV current timeout to assume it's night
#define TOUT_BATTRECHARGE			600		//600s/10m time limit for battery recharge
#define DUSK_TIME1					60*60	//60 minutes	delayed INV ON after dusk. in seconds
#define DUSK_TIME2					2*60*60	//2*60 minutes
#define DUSK_TIME3					3*60*60	//3h
#define DUSK_TIME4					4*60*60	//4h
#define DUSK_TIME5					5*60*60	//5h
#define DUSK_TIME6					6*60*60	//6h
#else						//TESTING VALUES

#define TICKS_ONESECOND	0	//counter ticks for one second (default 0)
#define TICKS_ONEMINUTE	22	//counter ticks for one minute (default 59)
#define TICKS_ONEHOUR	2	//counter ticks for one hour (default 59)
#define TICKS_ONEDAY	5	//counter ticks for one day (default 23)
#define RX_BFR_SIZE 127		//uart 1
#define TX_BFR_SIZE 1023		//uart 1
#define NO_FLASH_PAGES	52	//number of flash pages for storing statistics to flash
#define MOSFET_MAX_TEMP		50	//Mosfet max operating temperature *C
#define PV_CURRENT_MIN		320	//in 0.001A, min PV curent to assume that it is daylight - for alghorithm. after HAL_ADC_Calibration values for current circuit are of bigger values - instead 120mA it returns 350mA
								//current>PV_CURRENT_MIN to enter DAYTIME; (PV_CURRENT_MIN - PV_CURRENT_HYST) to keep "DAYTIME"; current<(PV_CURRENT_MIN - PV_CURRENT_HYST) to enter nightime; current<PV_CURRENT_MIN to keep nightime
								//this value sets minimal level of current that can make inverter working without excessive reactive power at mains side(AC current)
#define PV_CURRENT_HYST		70	//in 0.001A, PV curent hysteresis, to prevent frequent change chg/dschg during dusk and dawn
#define INV_CURRENT_MIN_DAY		200	//in 0.001A, min inverter current to assume that inv transfers energy to mains. usually slightly smaller than PV_CURRENT_MIN
								//to prevent switchung battery on/off at daytime at dusk . difference should cover current measurement error for small currents between channels
#define INV_CURRENT_MIN_NIGHT		250	//in 0.001A, min inverter current to assume that inv transfers energy to mains.
#define INV_CURRENT_MAX		1350	//in 0.001A, maximum inverter current during batttery discharging. Helps prevent overheating
#define INV_CURR_SC			1500	//in 0.001A, more than that is considered as short circuit, all will be shut down without delay (in 1 second)
#define PV_OCV_VOLGATE		435	//in 0.1V, OCV voltage for PV panel without load (minimal PV OCV voltage for hot, cloudy day)
#define PV_MIN_OP_VOLTAGE	330	//in 0.1V, minimal operational voltage for PV panel when working with inverter. prevents INV from overloading PV.
#define BATT_CRITICAL_MIN_VOLTAGE	15	//in 0.1V, min limit for charging
#define BATT_MIN_VOLTAGE	348	//in 0.1V, consider min limit for discharging with "-hysteresisMIN"
#define BATT_MAX_VOLTAGE	393	//in 0.1V, consider max limit for charging with "+hysteresisMAX"
#define BATT_VOLTAGE_MAXHYSTERESIS	18	//in 0.1V, to prevent frequent switching chg/dschg at max voltage
#define BATT_VOLTAGE_MINHYSTERESIS	17	//in 0.1V, to prevent frequent switching chg/dschg at min voltage/ 15 makes multiple discharges at dusk - confuses statistics; maybe longer nigh-timeout will help
#define SECONDS_HOUR		(TICKS_ONEMINUTE+1)*(TICKS_ONEHOUR+1)	//to calculate Watt-hours from Watt-seconds
#define LEDSTATUS_TIMER_LONG		9		//10 seconds cycle
#define LEDSTATUS_TIMER_MED			3		//4 seconds cycle
#define LEDSTATUS_TIMER_SHORT		1		//2 seconds cycle
#define TIME2RESET_INV				20	//30min/1800s, 42m/2500s; if INV not working for longer than ... seconds perform reset procedure
#define TIME2OVLD_INV				15		//maximum time of overload,seconds, during battery discharge
#define TIME_LOW_I_4NIGHT			18	//30min/1800s, 42m/2500s; low PV current timeout to assume it's night
#define TOUT_BATTRECHARGE			6		//600s/10m time limit for battery recharge
#define DUSK_TIME1					60	//60 minutes	delayed INV ON after dusk. in seconds
#define DUSK_TIME2					2*60	//2*60 minutes
#define DUSK_TIME3					3*60	//3h
#define DUSK_TIME4					4*60	//4h
#define DUSK_TIME5					5*60	//5h
#define DUSK_TIME6					6*60	//6h
#endif
#define CONFIG_MAINS_0DELAY			0		//state-mashine steps
#define CONFIG_MAINS_1DELAY			1
#define CONFIG_MAINS_2DELAY			2
#define CONFIG_MAINS_3DELAY			3
#define CONFIG_MAINS_4DELAY			4
#define CONFIG_MAINS_5DELAY			5
#define CONFIG_MAINS_6DELAY			6
#define CONFIG_BATT_0DELAY			7
#define CONFIG_BATT_1DELAY			8
#define CONFIG_BATT_2DELAY			9
#define CONFIG_BATT_3DELAY			10
#define CONFIG_BATT_4DELAY			11
#define CONFIG_BATT_5DELAY			12
#define CONFIG_BATT_6DELAY			13
#define CONFIG_MAINS_NOBATTDSCHG	14

__attribute__((__section__(".user_data"))) const char Stats_savedInFLASH[NO_FLASH_PAGES][FLASH_PAGE_SIZE];	//matrix in flash for statistics storage
__attribute__((__section__(".user_data"))) const char Cal_savedInFLASH[FLASH_PAGE_SIZE];	//data in flash for calibration values storage, size one full page
//compiling with GCC STM32CubeIDE: only without optimization makes flash reading function working properly
//any level of optimization makes flash reading function operate improperly (reading 0xFF)
//flash writing works good even with strong optimization
void __attribute__((optimize("O0"))) RestoreStatisticsFromFLASH();
void __attribute__((optimize("O0"))) RestoreCalValuesFromFLASH();
int __attribute__((optimize("O0"))) StoreStatistics2FLASH();
int __attribute__((optimize("O0"))) StoreCalData2FLASH();
/* USER CODE END PD */

 ADC_HandleTypeDef hadc1;
DMA_HandleTypeDef hdma_adc1;

TIM_HandleTypeDef htim2;
TIM_HandleTypeDef htim16;

UART_HandleTypeDef huart1;
DMA_HandleTypeDef hdma_usart1_rx;
DMA_HandleTypeDef hdma_usart1_tx;

/* Definitions for defaultTask */
osThreadId_t defaultTaskHandle;
const osThreadAttr_t defaultTask_attributes = {
  .name = "defaultTask",
  .stack_size = 1024 * 4,
  .priority = (osPriority_t) osPriorityNormal,
};
/* Definitions for myTimer01 */
osTimerId_t myTimer01Handle;
const osTimerAttr_t myTimer01_attributes = {
  .name = "myTimer01"
};
/* USER CODE BEGIN PV */
uint8_t RxRollover = 0;
uint8_t RxCounter = 0;
uint16_t RxBfrPos = 0;
uint8_t TxCounter = 0;
char TxBuffer[TX_BFR_SIZE];
uint8_t RxBuffer[RX_BFR_SIZE];
uint8_t ConfigReg;
uint32_t RecentPage_pointer;	//pointer to actual page adress (needs shifting to get direct adress)
uint32_t count_second=TICKS_ONESECOND, count_minutes=TICKS_ONEMINUTE, count_hours=TICKS_ONEHOUR, count_days=TICKS_ONEDAY;
uint32_t FlagBatteryMOS=0;		//flag indicating Mosfet status: ON 1 or OFF 0
uint32_t FlagInverterMOS=0;		//flag indicating Mosfet status: ON 1 or OFF 0
uint32_t FlagBackupMOS=0;		//flag indicating backup power mosfet status
uint32_t FlagExt_I=0;			//flag showing External reset input (reset microinverter) reading
uint32_t FlagExt_Ctrl=0;		//flag showing External Control input reading
uint32_t VoltHysteresisChg=0, VoltHysteresisDsChg=0;
uint32_t PVCurrentHysteresis=PV_CURRENT_HYST;
uint32_t LedStatus, LedStatusTimer;
uint32_t Flag_StoreStatistics=0;
uint32_t Flag_ShowStats=0;
uint32_t FlagRunMainLoop=0;			//flag to synhronize main loop with software timer procedure
uint32_t FlagResetInverter, TimeToResetInv=TIME2RESET_INV, BlankingTimeToResetInv=TIME2RESET_INV/3, StateResetInv;		//variables for resetInv procedure
typedef struct
{
	uint32_t Inv_current;
	uint32_t PV_current;
	uint32_t PV_voltage;
	uint32_t Batt_voltage;
	int NTC1_PCB;
	int NTC2_Inverter_mos;
	int NTC3_Battery_mos;
	uint32_t VrefInt;
}AdcConvertVals;
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
int main(void)
{
  /* MCU Configuration--------------------------------------------------------*/

  /* Reset of all peripherals, Initializes the Flash interface and the Systick. */
  HAL_Init();

  /* Configure the system clock */
  SystemClock_Config();

  /* Initialize all configured peripherals */
  MX_GPIO_Init();
  MX_DMA_Init();
  MX_ADC1_Init();
  MX_USART1_UART_Init();
  MX_TIM2_Init();
  MX_TIM16_Init();
  /* USER CODE BEGIN 2 */
#if HW_VER > 01
  GPIO_InitTypeDef GPIO_InitStruct = {0};
  GPIO_InitStruct.Pin = EXT_I_Pin;
  GPIO_InitStruct.Mode = GPIO_MODE_INPUT;
  GPIO_InitStruct.Pull = GPIO_NOPULL;
  HAL_GPIO_Init(EXT_I_GPIO_Port, &GPIO_InitStruct);
#endif
  /* USER CODE END 2 */

  /* Init scheduler */
  osKernelInitialize();

  /* USER CODE BEGIN RTOS_MUTEX */
  /* add mutexes, ... */
  /* USER CODE END RTOS_MUTEX */

  /* USER CODE BEGIN RTOS_SEMAPHORES */
  /* add semaphores, ... */
  /* USER CODE END RTOS_SEMAPHORES */

  /* Create the timer(s) */
  /* creation of myTimer01 */
  myTimer01Handle = osTimerNew(Callback01, osTimerPeriodic, NULL, &myTimer01_attributes);

  /* USER CODE BEGIN RTOS_TIMERS */
  /* start timers, add new ones, ... */
  /* USER CODE END RTOS_TIMERS */

  /* USER CODE BEGIN RTOS_QUEUES */
  /* add queues, ... */

  /* USER CODE END RTOS_QUEUES */

  /* Create the thread(s) */
  /* creation of defaultTask */
  defaultTaskHandle = osThreadNew(StartDefaultTask, NULL, &defaultTask_attributes);

  /* USER CODE BEGIN RTOS_THREADS */
  /* add threads, ... */
  /* USER CODE END RTOS_THREADS */

  /* USER CODE BEGIN RTOS_EVENTS */
  /* add events, ... */
  /* USER CODE END RTOS_EVENTS */

  /* Start scheduler */
  osKernelStart();

  /* We should never get here as control is now taken by the scheduler */
  /* Infinite loop */
  /* USER CODE BEGIN WHILE */
  while (1)
  {
    /* USER CODE END WHILE */

    /* USER CODE BEGIN 3 */
  }
  /* USER CODE END 3 */
}

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
/* USER CODE BEGIN 4 */

void HAL_UART_RxCpltCallback(UART_HandleTypeDef *huart) {
	// UART Rx Complete Callback;
	// Rx Complete is called by: DMA (automatically), if it rolls over
	// and when an IDLE Interrupt occurs
	// DMA Interrupt allays occurs BEFORE the idle interrupt can be fired because
	// idle detection needs at least one UART clock to detect the bus is idle. So
	// in the case, that the transmission length is one full buffer length
	// and the start buffer pointer is at 0, it will be also 0 at the end of the
	// transmission. In this case the DMA rollover will increment the RxRollover
	// variable first and len will not be zero.
	if(__HAL_UART_GET_FLAG(huart, UART_FLAG_IDLE)) {									// Check if it is an "Idle Interrupt"
		__HAL_UART_CLEAR_IDLEFLAG(&huart1);												// clear the interrupt
		RxCounter++;																	// increment the Rx Counter
//		uint8_t TxSize = 0;
		uint16_t start = RxBfrPos;														// Rx bytes start position (=last buffer position)
		RxBfrPos = RX_BFR_SIZE - (uint16_t)huart->hdmarx->Instance->CNDTR;				// determine actual buffer position
		uint16_t len = RX_BFR_SIZE;														// init len with max. size

		if(RxRollover < 2)  {
			if(RxRollover) {															// rolled over once
				if(RxBfrPos <= start) len = RxBfrPos + RX_BFR_SIZE - start;				// no bytes overwritten
				else len = RX_BFR_SIZE + 1;												// bytes overwritten error
			} else {
				len = RxBfrPos - start;													// no bytes overwritten
			}
		} else {
			len = RX_BFR_SIZE + 2;														// dual rollover error
		}

		if(len && (len <= RX_BFR_SIZE)) {
			// create response message
//			sprintf(TxBuffer, "ACK RxC:%d S:%d L:%d RO:%d RXp:%d >>", RxCounter, start, len, RxRollover, RxBfrPos);
//			TxSize = strlen(TxBuffer);
			// add received bytes to TxBuffer
//			uint8_t i;
//			for(i = 0; i < len; i++) *(TxBuffer + TxSize + i) = *(RxBuffer + ((start + i) % RX_BFR_SIZE));
//			TxSize += i;
			if (RxBuffer[start] == 'f' || RxBuffer[start] == 'F') Flag_ShowStats = 4;	//show statistics from Flash
			if (RxBuffer[start] == 'c' || RxBuffer[start] == 'C') Flag_ShowStats = 5;	//show current statistics
			if (RxBuffer[start] == 'w' || RxBuffer[start] == 'W') Flag_ShowStats = 3;	//show WattHours statistics
			if (RxBuffer[start] == 'e' || RxBuffer[start] == 'E')						//erase statistics in flash - only newest
			{
				uint32_t i, temp;
				temp = StatCurrentWh.FlashPageCounter;
				for(i = 0; i < sizeof(Stat_Flash); i++)		//clear statistics that will be stored in flash at top of the hour
				{
					((uint8_t *) &StatCurrentWh)[i] = 0;
					((uint8_t *) &Stat_Flash)[i] = 0;
				}
				StatCurrentWh.FlashPageCounter = temp;
				Stat_Flash.FlashPageCounter = temp;
				Flag_ShowStats = 4;
			}
			if (RxBuffer[start] == 'd' || RxBuffer[start] == 'D')						//delete current and historical statistics stored in flash
			{
				DeleteStatistics2FLASH();
				Flag_ShowStats = 4;
			}
			if (RxBuffer[start] == 'p' || RxBuffer[start] == 'P')						//show calibration data
			{
				Flag_ShowStats = 62;
			}
			if (RxBuffer[start] == 'o' || RxBuffer[start] == 'O')						//read calibration data from flash
			{
				Flag_ShowStats = 62;
				RestoreCalValuesFromFLASH();
			}
			if (RxBuffer[start] == 'l' || RxBuffer[start] == 'L')						//save calibration data
			{
				StoreCalData2FLASH();
				Flag_ShowStats = 62;
			}
			if (RxBuffer[start] == 'k' || RxBuffer[start] == 'K')						//save calibration data
			{
				Flag_ShowStats = 62;
				for(int i = 0; i < sizeof(CalibrationValues); i++)
				{
					((uint8_t *) &CalibrationValues)[i] = 0;
				}
			}
			if (RxBuffer[start] == 'B' || RxBuffer[start] == 'b')						//clear BlankTime
			{
				BlankingTimeToResetInv = 0;
			}
			if (RxBuffer[start] == 't' || RxBuffer[start] == 'T')						//clear time2resetInv
			{
				TimeToResetInv = 0;
			}
			if (RxBuffer[start] == '0')													//calibrate inverter "0" current
			{
				Flag_ShowStats = 62;
				uint32_t temp;
				temp = 	ConvertIValue(Adc1RawReadings.Inv_current);
				if (temp < 500)
				{
					CalibrationValues.Inv_current_off = (int)temp;
					sprintf(TxBuffer, "\r\nInverter current offset: %i\r\n",( int)temp);
				}
				else
				{
					sprintf(TxBuffer, "\r\nInverter Zero current too high: %i\r\n",( int)Adc1Measurements.Inv_current);
				}
			}
			if (RxBuffer[start] == '1')													//calibrate PV "0" current
			{
				Flag_ShowStats = 62;
				uint32_t temp;
				temp = 	ConvertIValue(Adc1RawReadings.PV_current);
				if (temp < 500)
				{
					CalibrationValues.PV_current_off = (int)temp;
					sprintf(TxBuffer, "\r\nPV current offset: %i\r\n",( int)temp);
				}
				else
				{
					sprintf(TxBuffer, "\r\nPV Zero current too high: %i\r\n",( int)Adc1Measurements.PV_current);
				}
			}
			if (RxBuffer[start] == '5')													//toggle on/off under-temperature limit for charging
			{
				Flag_ShowStats = 62;
				if (CalibrationValues.UnderTempLimit4Charging) CalibrationValues.UnderTempLimit4Charging=0;
				else CalibrationValues.UnderTempLimit4Charging=1;
				RxBuffer[start] = 'h';		//workaround to show help and variable status
			}
			if (RxBuffer[start] == 'h' || RxBuffer[start] == 'H' || RxBuffer[start] == '?')
			{
				Flag_ShowStats = 60;
				sprintf(TxBuffer, "\r\nhelp: \r\n"
						"H - show this help\r\n"
						"C - show configuration and firmware version\r\n"
						"F - show last statistics stored in Flash mem\r\n"
						"E - erase current stat values stored in flash, will be saved at top of the hour. FlashPageCounter will be preserved, historical data preserved\r\n"
						"D - Delete all stat data saved in flash, current and historical, instantly, !irreversible!\r\n"
						"W - show Watt-Hours stat\r\n"
						"0 - calibrate 'zero' current level for Inverter\r\n"
						"1 - calibrate 'zero' current level for PV\r\n"
						"P - show calibration values\r\n"
						"O - read calibration values from Flash\r\n"
						"K - clear calibration values (not saved)\r\n"
						"L - save calibration values\r\n"
						"B - clear BlankingTimeToResetInv\r\n"
						"T - clear Time2ResetInv\r\n"
						"5 - /ON '1' or 'ff'/ /OFF '0'/ under-temp limit for batt charging, currently: %u\r\n"
						"\r\n"
						,CalibrationValues.UnderTempLimit4Charging
						);
			}
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

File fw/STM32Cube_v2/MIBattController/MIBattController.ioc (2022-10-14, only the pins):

Mcu.UserName=STM32L431RCTx
PA0.Signal=ADCx_IN5
PA1.Signal=ADCx_IN6
PA10.Signal=USART1_RX
PA2.Signal=ADCx_IN7
PA3.GPIO_Label=EXT_CTRL
PA3.Signal=GPIO_Input
PA4.GPIO_Label=BATT_BCKP_DRV
PA4.Signal=GPIO_Output
PA5.GPIO_Label=BAT_SWITCH_PWM
PA5.Signal=S_TIM2_CH1
PA6.GPIO_Label=BAT_SWITCH_OFF
PA6.Signal=GPIO_Output
PA7.GPIO_Label=INV_SWITCH_DRV
PA7.Signal=GPIO_Output
PA8.GPIO_Label=MEAS_PWR
PA8.Signal=GPIO_Output
PA9.Signal=USART1_TX
PB0.GPIO_Label=C4
PB0.Signal=GPIO_Input
PB1.GPIO_Label=C2
PB1.Signal=GPIO_Input
PB12.GPIO_Label=LED4
PB12.Signal=GPIO_Output
PB13.GPIO_Label=LED3
PB13.Signal=GPIO_Output
PB14.GPIO_Label=LED2
PB14.Signal=GPIO_Output
PB15.GPIO_Label=LED1
PB15.Signal=GPIO_Output
PB2.GPIO_Label=CD
PB2.Signal=GPIO_Input
PB8.GPIO_Label=EXT_O
PB8.Signal=S_TIM16_CH1
PB9.GPIO_Label=EXT_I
PB9.Signal=GPIO_Input
PC0.Signal=ADCx_IN1
PC1.Signal=ADCx_IN2
PC2.Signal=ADCx_IN3
PC3.Signal=ADCx_IN4
PC4.GPIO_Label=C3
PC4.Signal=GPIO_Input
PC5.GPIO_Label=C1
PC5.Signal=GPIO_Input

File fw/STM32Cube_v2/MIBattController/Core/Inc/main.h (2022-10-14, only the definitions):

#define EXT_CTRL_Pin GPIO_PIN_3
#define EXT_CTRL_GPIO_Port GPIOA
#define BATT_BCKP_DRV_Pin GPIO_PIN_4
#define BATT_BCKP_DRV_GPIO_Port GPIOA
#define BAT_SWITCH_PWM_Pin GPIO_PIN_5
#define BAT_SWITCH_PWM_GPIO_Port GPIOA
#define BAT_SWITCH_OFF_Pin GPIO_PIN_6
#define BAT_SWITCH_OFF_GPIO_Port GPIOA
#define INV_SWITCH_DRV_Pin GPIO_PIN_7
#define INV_SWITCH_DRV_GPIO_Port GPIOA
#define C3_Pin GPIO_PIN_4
#define C3_GPIO_Port GPIOC
#define C1_Pin GPIO_PIN_5
#define C1_GPIO_Port GPIOC
#define C4_Pin GPIO_PIN_0
#define C4_GPIO_Port GPIOB
#define C2_Pin GPIO_PIN_1
#define C2_GPIO_Port GPIOB
#define CD_Pin GPIO_PIN_2
#define CD_GPIO_Port GPIOB
#define LED4_Pin GPIO_PIN_12
#define LED4_GPIO_Port GPIOB
#define LED3_Pin GPIO_PIN_13
#define LED3_GPIO_Port GPIOB
#define LED2_Pin GPIO_PIN_14
#define LED2_GPIO_Port GPIOB
#define LED1_Pin GPIO_PIN_15
#define LED1_GPIO_Port GPIOB
#define MEAS_PWR_Pin GPIO_PIN_8
#define MEAS_PWR_GPIO_Port GPIOA
#define EXT_O_Pin GPIO_PIN_8
#define EXT_O_GPIO_Port GPIOB
#define EXT_I_Pin GPIO_PIN_9
#define EXT_I_GPIO_Port GPIOB

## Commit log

2022-07-26 HW design source files in Altium.
    [Battery_4_mI_R1.PrjPcb, Battery_4_mI_R2.PrjPcb, microInv_batt_controller.PcbDoc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]
2022-07-26 gerbers. ready to order ;-)
2022-08-07 added daytime lenght measurrement, to-be-tested corrected uptime conting over 24h added short-circuit flag for fast reaction to that condition and longer timeouts when SC occurs added pull-up on UART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
    [MIBattController.ioc, main.c]
2022-08-19 corrected daytime measurement added current measurement offset calibration
    [MIBattController.ioc, main.c]
2022-08-22 updated chg statistics saving added PV current hysteresis to prevent frequent change day/nigh mode at dusk and dawn
    [main.c]
2022-08-23 corrected inverter reset function in night mode. before correction it was toggiling Inverter power instead waiting full timeout at it should.
    [main.c]
2022-08-30 added nightime inverter reset function when 'no current' to inverter feature added and corrected ;-)
    [main.c]
2022-09-21 added blanking time to prevent frequent resets from EXT_I
    [main.c]
2022-09-21 corrected issue with flash memory saving function (stopping swTimer caused hardFault)
    [main.c]
2022-10-14 Added under temperature battery charging protection - behavior can be controlled thru consore. to do: calibration of NTC sensor, for temperatures <20*C in very inacurate
2022-10-14 Wh calculation fix (not tested yet)
    [main.c]
2022-10-20 under temperature battery protection feature messed with regulat over voltage protection... fixing that
    [main.c]
2022-10-27 new equation to calculate temperature from NTC ADC value. Tested in range -20*C to +25*C, real precision +/- 2*C (depends on NTC sample) added low temperature protection for all modes of operation (t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
2022-11-14 added TempNoBatt2chargeUndertemp variable printf NTC equation confirmed in temperature range -20 to +20*C
2023-04-06 New APS microinverter firmware requires longer time for sync with mains -> timeout extended to 70 seconds, to allow that sync. updated LED status blinking procedure, now shows under temperature condi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

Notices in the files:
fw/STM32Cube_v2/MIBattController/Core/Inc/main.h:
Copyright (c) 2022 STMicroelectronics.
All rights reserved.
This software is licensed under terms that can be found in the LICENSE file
